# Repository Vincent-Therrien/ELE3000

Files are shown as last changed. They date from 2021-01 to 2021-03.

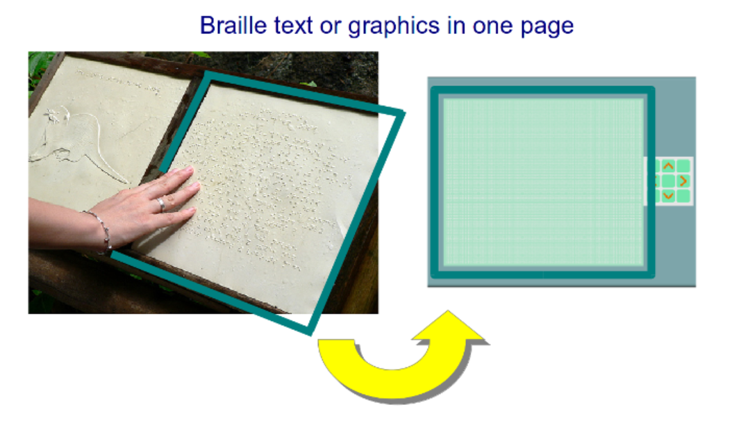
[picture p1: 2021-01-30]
html/_images/tactis_table.PNG

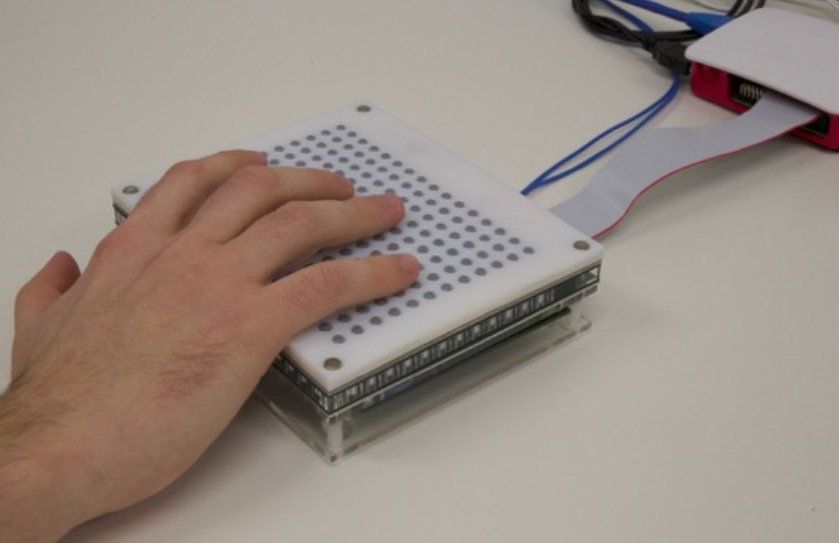
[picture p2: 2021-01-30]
html/_images/blindpad.PNG

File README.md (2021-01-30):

# ELE3000
Projet de troisième année à Polytechnique Montréal par
Vincent Therrien (vincent.therrien@polymtl.ca)

La documentation est générée avec le programme Sphinx, utilisé pour générer
la documentation officielle de Python. Les fichiers source sont écrits avec
la syntaxe Restructured Text (rst) et la documentation peut être compilée sous
plusieurs formes.

## Documentation HTML

Ouvrez le fichier "html/index.html" pour consulter la documentation sous format
HTML.

## Documentation PDF

Ouvrez le fichier "ele3000_latex.pdf" pour consulter la documentation en PDF.

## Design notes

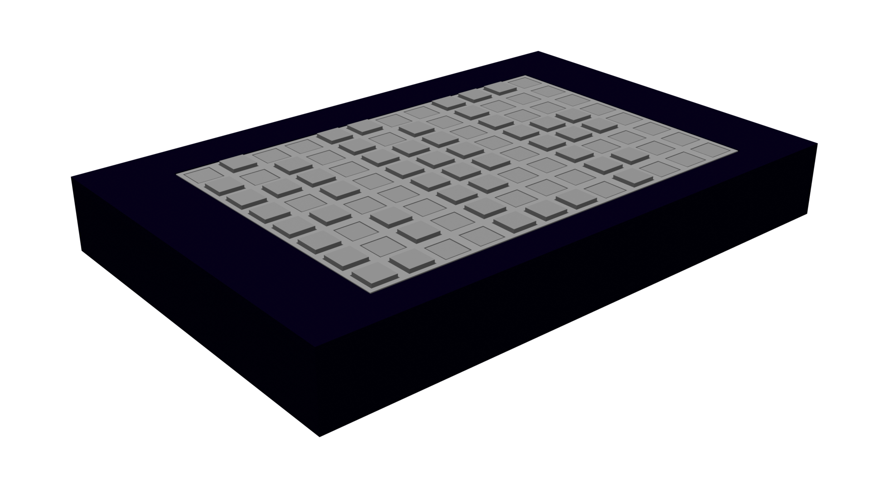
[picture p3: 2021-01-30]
html/_images/simple.png

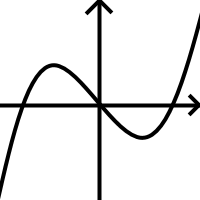
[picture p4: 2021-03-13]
application/assets/examples/degre_trois.png

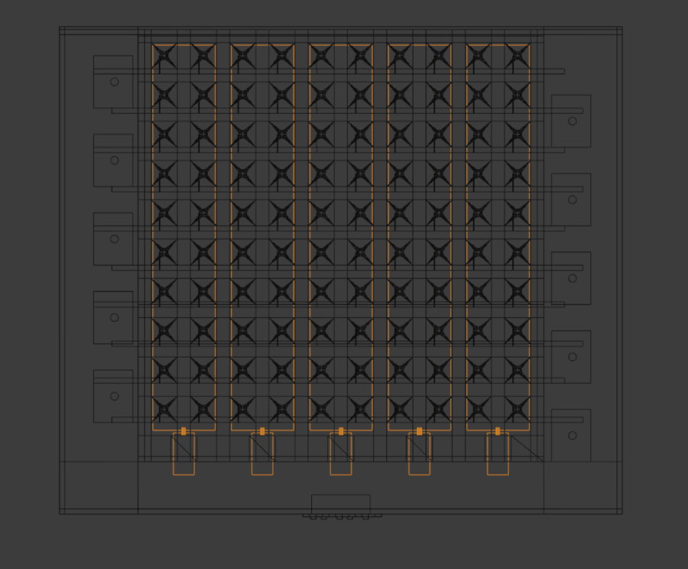
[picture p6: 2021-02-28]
html/_images/plateformes.png

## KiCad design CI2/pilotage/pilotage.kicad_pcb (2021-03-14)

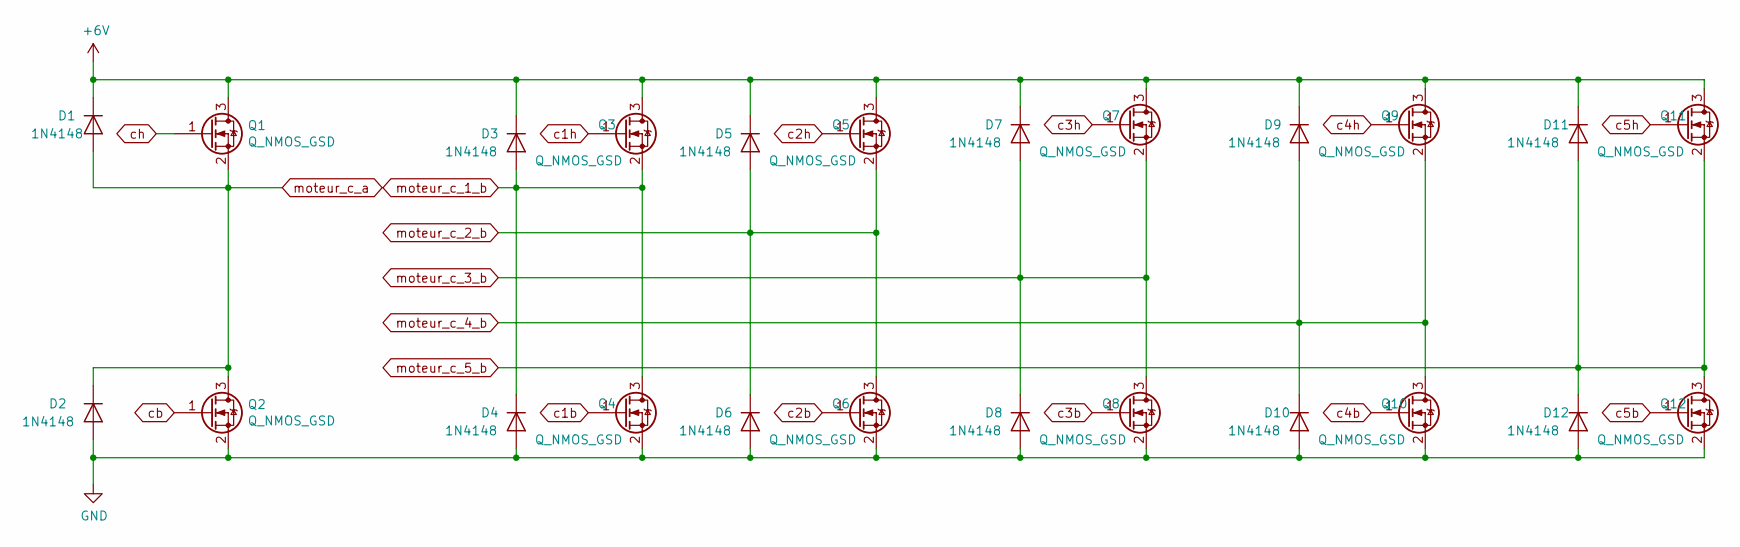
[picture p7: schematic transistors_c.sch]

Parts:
D1, D2, D3, D4, D5, D6, D7, D8, D9, D10, D11, D12: 1N4148; D_SOD-323_HandSoldering; Manufacturer Part Number 1N4148WS; DigiKey 1N4148WSFSCT-ND
Q1, Q2, Q3, Q4, Q5, Q6, Q7, Q8, Q9, Q10, Q11, Q12: Q_NMOS_GSD; SOT-23; Manufacturer Part Number DMN3404L-7; DigiKey DMN3404LDICT-ND

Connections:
+6V: D1.1 (K), D3.1 (K), D5.1 (K), D7.1 (K), D9.1 (K), D11.1 (K), Q1.3 (D), Q3.3 (D), Q5.3 (D), Q7.3 (D), Q9.3 (D), Q11.3 (D); also elsewhere on the board
GND: D2.2 (A), D4.2 (A), D6.2 (A), D8.2 (A), D10.2 (A), D12.2 (A), Q2.2 (S), Q4.2 (S), Q6.2 (S), Q8.2 (S), Q10.2 (S), Q12.2 (S); also elsewhere on the board
c1b: Q4.1 (G); also elsewhere on the board
c1h: Q3.1 (G); also elsewhere on the board
c2b: Q6.1 (G); also elsewhere on the board
c2h: Q5.1 (G); also elsewhere on the board
c3b: Q8.1 (G); also elsewhere on the board
c3h: Q7.1 (G); also elsewhere on the board
c4b: Q10.1 (G); also elsewhere on the board
c4h: Q9.1 (G); also elsewhere on the board
c5b: Q12.1 (G); also elsewhere on the board
c5h: Q11.1 (G); also elsewhere on the board
cb: Q2.1 (G); also elsewhere on the board
ch: Q1.1 (G); also elsewhere on the board
moteur_c_1_b: D3.2 (A), D4.1 (K), Q3.2 (S), Q4.3 (D); also elsewhere on the board
moteur_c_2_b: D5.2 (A), D6.1 (K), Q5.2 (S), Q6.3 (D); also elsewhere on the board
moteur_c_3_b: D7.2 (A), D8.1 (K), Q7.2 (S), Q8.3 (D); also elsewhere on the board
moteur_c_4_b: D9.2 (A), D10.1 (K), Q9.2 (S), Q10.3 (D); also elsewhere on the board
moteur_c_5_b: D11.2 (A), D12.1 (K), Q11.2 (S), Q12.3 (D); also elsewhere on the board
moteur_c_a: D1.2 (A), D2.1 (K), Q1.2 (S), Q2.3 (D); also elsewhere on the board

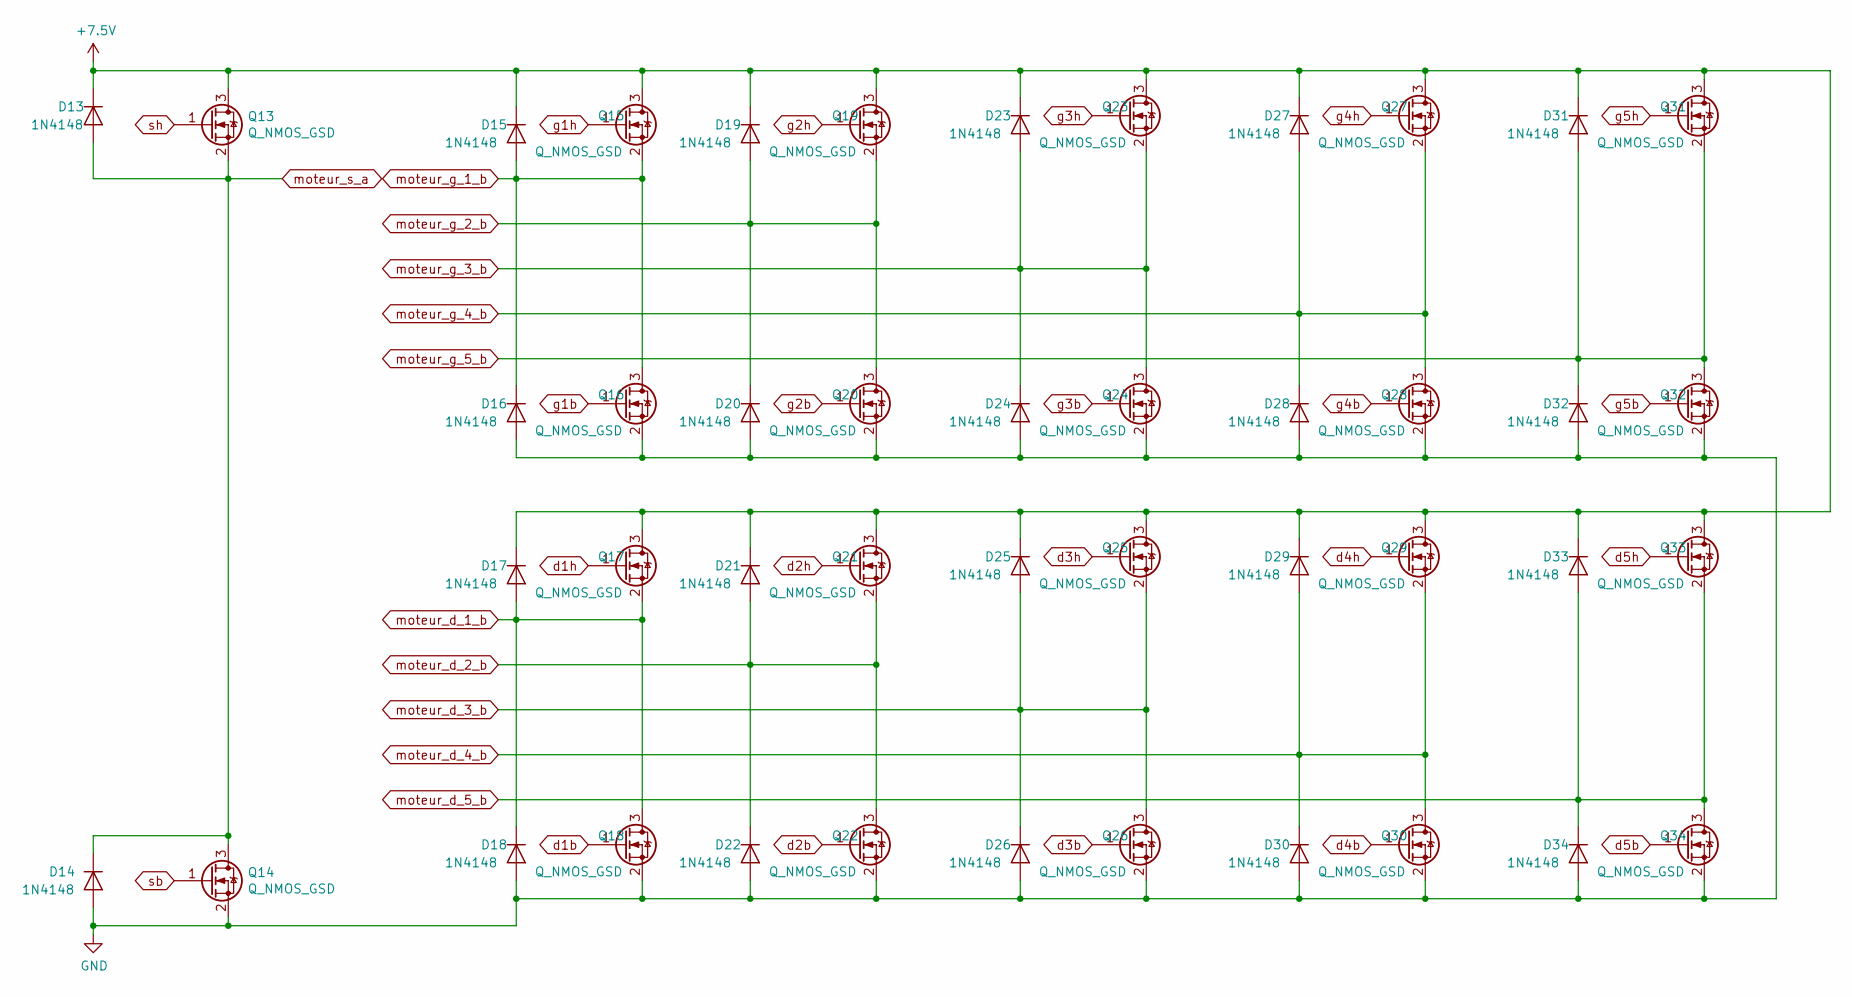
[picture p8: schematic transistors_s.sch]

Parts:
D13, D14, D15, D16, D17, D18, D19, D20, D21, D22, D23, D24, D25, D26, D27, D28, D29, D30, D31, D32, D33, D34: 1N4148; D_SOD-323_HandSoldering; Manufacturer Part Number 1N4148WS; DigiKey 1N4148WSFSCT-ND
Q13, Q14, Q15, Q16, Q17, Q18, Q19, Q20, Q21, Q22, Q23, Q24, Q25, Q26, Q27, Q28, Q29, Q30, Q31, Q32, Q33, Q34: Q_NMOS_GSD; SOT-23; Manufacturer Part Number DMN3404L-7; DigiKey DMN3404LDICT-ND

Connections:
+7.5V: D13.1 (K), D15.1 (K), D17.1 (K), D19.1 (K), D21.1 (K), D23.1 (K), D25.1 (K), D27.1 (K), D29.1 (K), D31.1 (K), D33.1 (K), Q13.3 (D), Q15.3 (D), Q17.3 (D), Q19.3 (D), Q21.3 (D), Q23.3 (D), Q25.3 (D), Q27.3 (D), Q29.3 (D), Q31.3 (D), Q33.3 (D); also elsewhere on the board
GND: D14.2 (A), D16.2 (A), D18.2 (A), D20.2 (A), D22.2 (A), D24.2 (A), D26.2 (A), D28.2 (A), D30.2 (A), D32.2 (A), D34.2 (A), Q14.2 (S), Q16.2 (S), Q18.2 (S), Q20.2 (S), Q22.2 (S), Q24.2 (S), Q26.2 (S), Q28.2 (S), Q30.2 (S), Q32.2 (S), Q34.2 (S); also elsewhere on the board
d1b: Q18.1 (G); also elsewhere on the board
d1h: Q17.1 (G); also elsewhere on the board
d2b: Q22.1 (G); also elsewhere on the board
d2h: Q21.1 (G); also elsewhere on the board
d3b: Q26.1 (G); also elsewhere on the board
d3h: Q25.1 (G); also elsewhere on the board
d4b: Q30.1 (G); also elsewhere on the board
d4h: Q29.1 (G); also elsewhere on the board
d5b: Q34.1 (G); also elsewhere on the board
d5h: Q33.1 (G); also elsewhere on the board
g1b: Q16.1 (G); also elsewhere on the board
g1h: Q15.1 (G); also elsewhere on the board
g2b: Q20.1 (G); also elsewhere on the board
g2h: Q19.1 (G); also elsewhere on the board
g3b: Q24.1 (G); also elsewhere on the board
g3h: Q23.1 (G); also elsewhere on the board
g4b: Q28.1 (G); also elsewhere on the board
g4h: Q27.1 (G); also elsewhere on the board
g5b: Q32.1 (G); also elsewhere on the board
g5h: Q31.1 (G); also elsewhere on the board
moteur_d_1_b: D17.2 (A), D18.1 (K), Q17.2 (S), Q18.3 (D); also elsewhere on the board
moteur_d_2_b: D21.2 (A), D22.1 (K), Q21.2 (S), Q22.3 (D); also elsewhere on the board
moteur_d_3_b: D25.2 (A), D26.1 (K), Q25.2 (S), Q26.3 (D); also elsewhere on the board
moteur_d_4_b: D29.2 (A), D30.1 (K), Q29.2 (S), Q30.3 (D); also elsewhere on the board
moteur_d_5_b: D33.2 (A), D34.1 (K), Q33.2 (S), Q34.3 (D); also elsewhere on the board
moteur_g_1_b: D15.2 (A), D16.1 (K), Q15.2 (S), Q16.3 (D); also elsewhere on the board
moteur_g_2_b: D19.2 (A), D20.1 (K), Q19.2 (S), Q20.3 (D); also elsewhere on the board
moteur_g_3_b: D23.2 (A), D24.1 (K), Q23.2 (S), Q24.3 (D); also elsewhere on the board
moteur_g_4_b: D27.2 (A), D28.1 (K), Q27.2 (S), Q28.3 (D); also elsewhere on the board
moteur_g_5_b: D31.2 (A), D32.1 (K), Q31.2 (S), Q32.3 (D); also elsewhere on the board
moteur_s_a: D13.2 (A), D14.1 (K), Q13.2 (S), Q14.3 (D); also elsewhere on the board
sb: Q14.1 (G); also elsewhere on the board
sh: Q13.1 (G); also elsewhere on the board

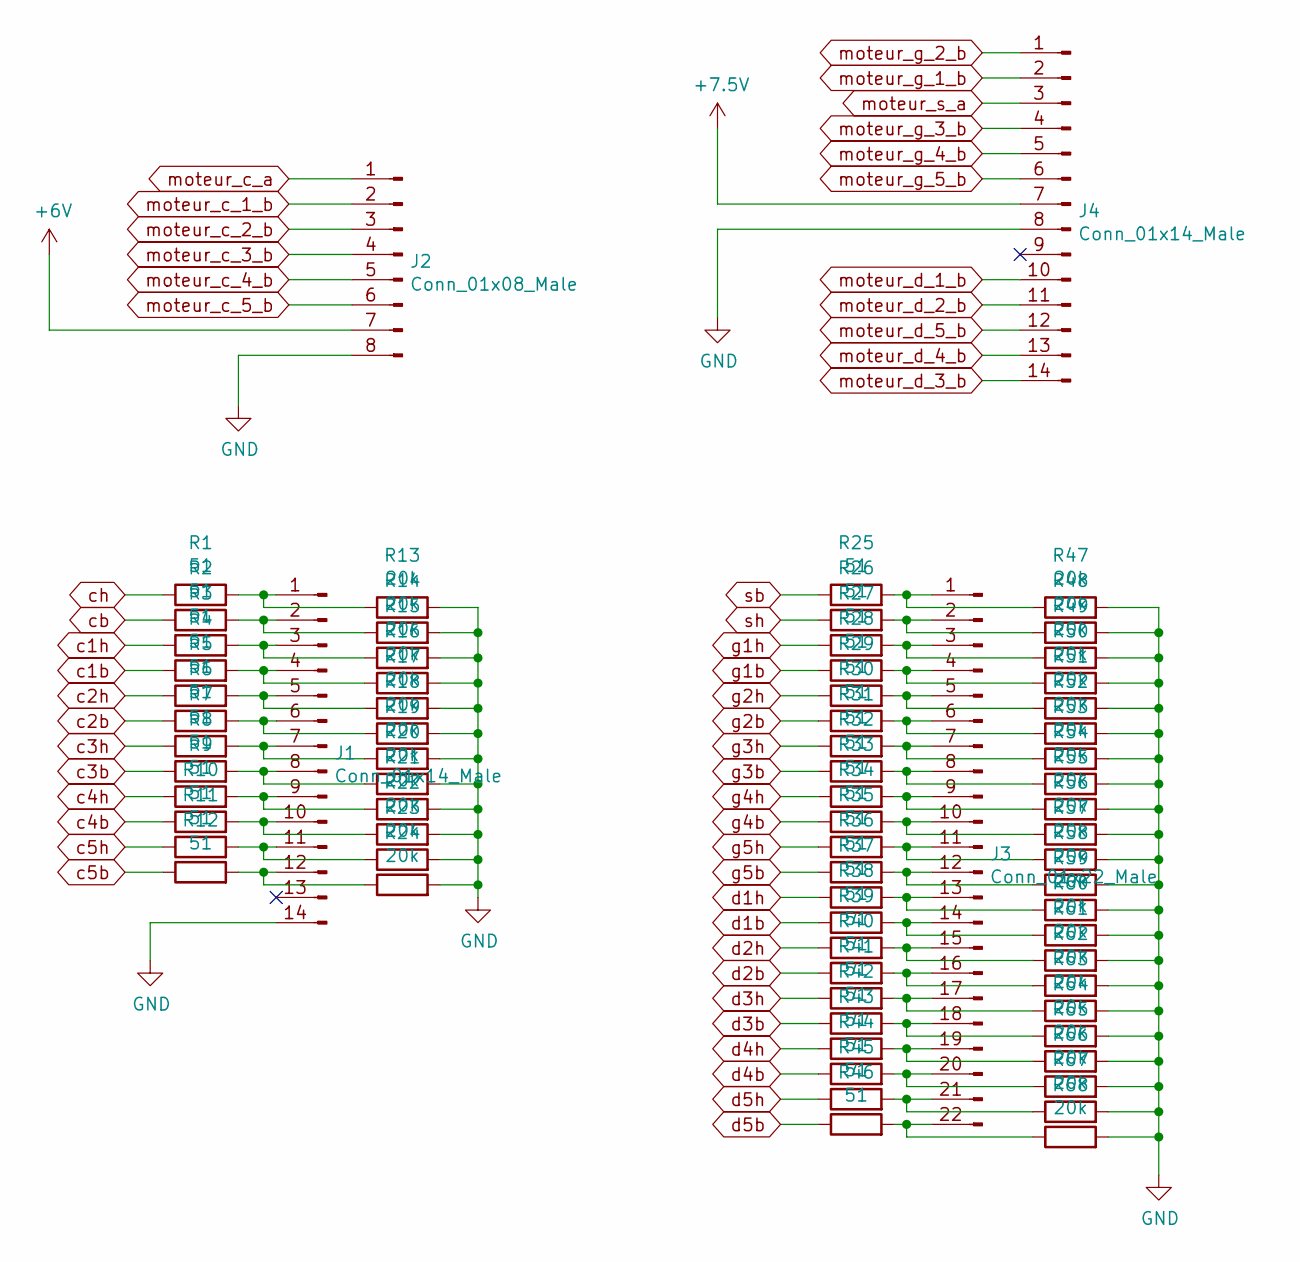
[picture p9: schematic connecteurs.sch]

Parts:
J1, J4: Conn_01x14_Male; PinHeader_1x14_P2.54mm_Vertical; Manufacturer Part Number PH1-14-UA; DigiKey 2057-PH1-14-UA-ND
J2: Conn_01x08_Male; PinHeader_1x08_P2.54mm_Vertical; Manufacturer Part Number PH1-08-UA; DigiKey 2057-PH1-08-UA-ND
J3: Conn_01x22_Male; PinHeader_1x22_P2.54mm_Vertical; Manufacturer Part Number 68000-122HLF; DigiKey 609-68000-122HLF-ND
R1, R2, R3, R4, R5, R6, R7, R8, R9, R10, R11, R12, R25, R26, R27, R28, R29, R30, R31, R32, R33, R34, R35, R36, R37, R38, R39, R40, R41, R42, R43, R44, R45, R46: 51; R_0805_2012Metric_Pad1.15x1.40mm_HandSolder; Manufacturer Part Number ESR10EZPJ510; DigiKey RHM51KCT-ND
R13, R14, R15, R16, R17, R18, R19, R20, R21, R22, R23, R24, R47, R48, R49, R50, R51, R52, R53, R54, R55, R56, R57, R58, R59, R60, R61, R62, R63, R64, R65, R66, R67, R68: 20k; R_0805_2012Metric_Pad1.15x1.40mm_HandSolder; Manufacturer Part Number ERJ-6GEYJ203V; DigiKey P20KACT-ND

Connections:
+6V: J2.7; also elsewhere on the board
+7.5V: J4.7; also elsewhere on the board
GND: J1.14, J2.8, J4.8, R13.2, R14.2, R15.2, R16.2, R17.2, R18.2, R19.2, R20.2, R21.2, R22.2, R23.2, R24.2, R47.2, R48.2, R49.2, R50.2, R51.2, R52.2, R53.2, R54.2, R55.2, R56.2, R57.2, R58.2, R59.2, R60.2, R61.2, R62.2, R63.2, R64.2, R65.2, R66.2, R67.2, R68.2; also elsewhere on the board
unnamed: J1.1, R1.2, R13.1
unnamed: J1.2, R2.2, R14.1
unnamed: J1.3, R3.2, R15.1
unnamed: J1.4, R4.2, R16.1
unnamed: J1.5, R5.2, R17.1
unnamed: J1.6, R6.2, R18.1
unnamed: J1.7, R7.2, R19.1
unnamed: J1.8, R8.2, R20.1
unnamed: J1.9, R9.2, R21.1
unnamed: J1.10, R10.2, R22.1
unnamed: J1.11, R11.2, R23.1
unnamed: J1.12, R12.2, R24.1
unnamed: J3.1, R25.2, R47.1
unnamed: J3.2, R26.2, R48.1
unnamed: J3.3, R27.2, R49.1
unnamed: J3.4, R28.2, R50.1
unnamed: J3.5, R29.2, R51.1
unnamed: J3.6, R30.2, R52.1
unnamed: J3.7, R31.2, R53.1
unnamed: J3.8, R32.2, R54.1
unnamed: J3.9, R33.2, R55.1
unnamed: J3.10, R34.2, R56.1
unnamed: J3.11, R35.2, R57.1
unnamed: J3.12, R36.2, R58.1
unnamed: J3.13, R37.2, R59.1
unnamed: J3.14, R38.2, R60.1
unnamed: J3.15, R39.2, R61.1
unnamed: J3.16, R40.2, R62.1
unnamed: J3.17, R41.2, R63.1
unnamed: J3.18, R42.2, R64.1
unnamed: J3.19, R43.2, R65.1
unnamed: J3.20, R44.2, R66.1
unnamed: J3.21, R45.2, R67.1
unnamed: J3.22, R46.2, R68.1
c1b: R4.1; also elsewhere on the board
c1h: R3.1; also elsewhere on the board
c2b: R6.1; also elsewhere on the board
c2h: R5.1; also elsewhere on the board
c3b: R8.1; also elsewhere on the board
c3h: R7.1; also elsewhere on the board
c4b: R10.1; also elsewhere on the board
c4h: R9.1; also elsewhere on the board
c5b: R12.1; also elsewhere on the board
c5h: R11.1; also elsewhere on the board
cb: R2.1; also elsewhere on the board
ch: R1.1; also elsewhere on the board
d1b: R38.1; also elsewhere on the board
d1h: R37.1; also elsewhere on the board
d2b: R40.1; also elsewhere on the board
d2h: R39.1; also elsewhere on the board
d3b: R42.1; also elsewhere on the board
d3h: R41.1; also elsewhere on the board
d4b: R44.1; also elsewhere on the board
d4h: R43.1; also elsewhere on the board
d5b: R46.1; also elsewhere on the board
d5h: R45.1; also elsewhere on the board
g1b: R28.1; also elsewhere on the board
g1h: R27.1; also elsewhere on the board
g2b: R30.1; also elsewhere on the board
g2h: R29.1; also elsewhere on the board
g3b: R32.1; also elsewhere on the board
g3h: R31.1; also elsewhere on the board
g4b: R34.1; also elsewhere on the board
g4h: R33.1; also elsewhere on the board
g5b: R36.1; also elsewhere on the board
g5h: R35.1; also elsewhere on the board
moteur_c_1_b: J2.2; also elsewhere on the board
moteur_c_2_b: J2.3; also elsewhere on the board
moteur_c_3_b: J2.4; also elsewhere on the board
moteur_c_4_b: J2.5; also elsewhere on the board
moteur_c_5_b: J2.6; also elsewhere on the board
moteur_c_a: J2.1; also elsewhere on the board
moteur_d_1_b: J4.10; also elsewhere on the board
moteur_d_2_b: J4.11; also elsewhere on the board
moteur_d_3_b: J4.14; also elsewhere on the board
moteur_d_4_b: J4.13; also elsewhere on the board
moteur_d_5_b: J4.12; also elsewhere on the board
moteur_g_1_b: J4.2; also elsewhere on the board
moteur_g_2_b: J4.1; also elsewhere on the board
moteur_g_3_b: J4.4; also elsewhere on the board
moteur_g_4_b: J4.5; also elsewhere on the board
moteur_g_5_b: J4.6; also elsewhere on the board
moteur_s_a: J4.3; also elsewhere on the board
sb: R25.1; also elsewhere on the board
sh: R26.1; also elsewhere on the board

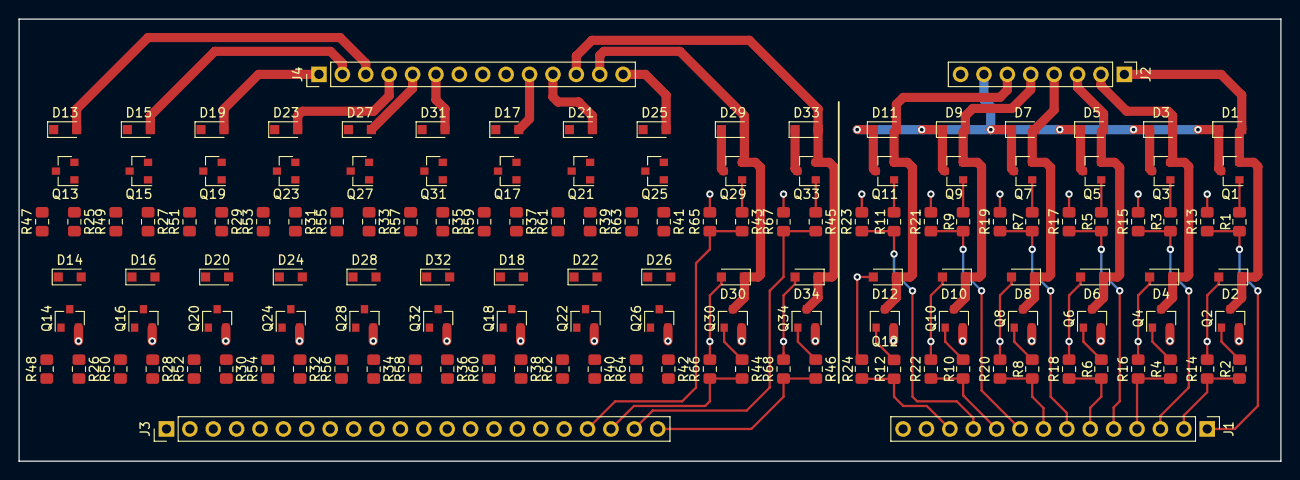
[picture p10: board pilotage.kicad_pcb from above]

Board: 2 copper layers, 137.0 x 48.0 mm, 140 parts (0 on the bottom side), 88 nets.

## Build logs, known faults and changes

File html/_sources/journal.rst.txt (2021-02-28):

Journaux hebdomadaires
======================

Janvier
-------

23
++

- Cours initial (présentation du cours et des objectifs de la semaine)
- Rédaction d'un document PDF de présentation sommaire du projet
- Recherche d'un professeur potentiellement intéressé par le projet
  dans la liste du personnel du département de GE
  (https://www.polymtl.ca/ge/notre-departement)
- Contact du professeur Richard Gourdeau et confirmation de sa direction
  du projet
- Rédaction de la description du projet ainsi que de l'échéancier;
  signature du professeur Gourdeau
- Création du journal

25
++

- Lecture sur les méthodologies de conception et le développement durable
- Second cours : validation de l'idée

27
++

- Commande de moteurs miniature pour les tester comme actionneurs
- Recherche sur les applications graphiques accessibles

30
++

- Fin de la recherche, génération de la documentation Latex

Février
-------

2
+++

- Tests mécaniques avec les moteurs.
- La force de moteurs est trop faible pour le concept initial, c'est pourquoi
  j'ai décrit une modification du concept dans la section plans.

6
+++

- Début de la réalisation des plans de l'appareil

7
+++

- Rédaction des spécifications fonctionnelles

Mars
----

Avril
-----

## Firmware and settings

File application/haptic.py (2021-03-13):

import os
import sys
import wx
import cv2
import json
import serial

def scale_bitmap(bitmap, width, height):
    image = bitmap.ConvertToImage()
    image = image.Scale(width, height, wx.IMAGE_QUALITY_HIGH)
    result = wx.Bitmap(image)
    return result

class DeviceInfo(wx.Frame):
    def __init__(self, windowTitle, strings):
        wx.Frame.__init__(self, None, title=windowTitle)
        content = ""
        for key, value in strings.items():
            content += key + "\t\t"
            if len(key) < 7:
                content += "\t"
            content += value + "\n\n"
        lbl = wx.StaticText(self, style = wx.ALIGN_LEFT | wx.EXPAND, size = (500, 500))
        lbl.SetLabel(content)
        self.Centre()
        self.Bind(wx.EVT_KEY_DOWN, self.OnKey)
    
    def OnKey(self, event):
        # Ctrl + x
        if event.ControlDown() and event.GetKeyCode() == 88:
            self.Close()
        else:
            event.Skip()


class MainFrame(wx.Frame):

    def __init__(self, *args, **kwargs):
        super(MainFrame, self).__init__(*args, **kwargs)
        # Retrieve user settings
        self.settings = {}
        with open('assets/settings.json') as f:
            self.settings = json.load(f)
        self.lexicon = {}
        self.setLanguage()
        # Runtime data
        self.cellArray = [
            [0, 0, 0, 0, 0, 0, 0, 0, 0, 0],
            [0, 0, 0, 0, 0, 0, 0, 0, 0, 0],
            [0, 0, 0, 0, 0, 0, 0, 0, 0, 0],
            [0, 0, 0, 0, 0, 0, 0, 0, 0, 0],
            [0, 0, 0, 0, 0, 0, 0, 0, 0, 0],
            [0, 0, 0, 0, 0, 0, 0, 0, 0, 0],
            [0, 0, 0, 0, 0, 0, 0, 0, 0, 0],
            [0, 0, 0, 0, 0, 0, 0, 0, 0, 0],
            [0, 0, 0, 0, 0, 0, 0, 0, 0, 0],
            [0, 0, 0, 0, 0, 0, 0, 0, 0, 0],
        ]
        self.nCol = 10
        self.nRow = 10
        self.imagePath = None
        self.subImages = []
        self.focusRectIndex = [0, 0]
        self.dimension = 1
        self.serialPort = None
        self.connectUtility = wx.CallLater(1000, self.connect)
        # Create application components.
        self.SetIcon(wx.Icon("assets/icon.png"))
        self.Centre()
        self.InitUI()
        self.SetTitle(self.lexicon["Title"])
        self.SetSize((900, 450))
        self.Centre()
        self.Bind(wx.EVT_PAINT, self.OnPaint)
        self.Bind(wx.EVT_SIZE, self.refresh)
        self.Bind(wx.EVT_KEY_DOWN, self.OnKey)
    
    def refresh(self, arg):
        self.Refresh()
        self.drawImage()
        self.refreshCells()
        self.SetFocus()
    
    def OnKey(self, event):
        # CTRL + open
        if event.ControlDown() and event.GetKeyCode() == 79:
            self.OnOpen(event)
        # CTRL info
        elif event.ControlDown() and event.GetKeyCode() == 73:
            self.OnDeviceInfo(event)
        # CTRL x
        elif event.ControlDown() and event.GetKeyCode() == 88:
            self.Close()
        # numbers
        elif event.GetKeyCode() > 48 and event.GetKeyCode() < 58:
            self.dimension = event.GetKeyCode() - 48
            self.focusRectIndex = [0, 0]
            self.refreshCells()
            self.refresh(None)
        # arrows
        elif event.GetKeyCode() == wx.WXK_DOWN:
            self.navigate('down')
        elif event.GetKeyCode() == wx.WXK_UP:
            self.navigate('up')
        elif event.GetKeyCode() == wx.WXK_LEFT:
            self.navigate('left')
        elif event.GetKeyCode() == wx.WXK_RIGHT:
            self.navigate('right')
        # Transmit image
        elif event.GetKeyCode() == wx.WXK_RETURN:
            self.transmit()
        else:
            event.Skip()

    def navigate(self, direction):
        if direction == 'down':
            self.focusRectIndex[1] += 1
            if self.focusRectIndex[1] >= self.dimension:
                self.focusRectIndex[1] = self.dimension - 1
        if direction == 'up':
            self.focusRectIndex[1] -= 1
            if self.focusRectIndex[1] < 0:
                self.focusRectIndex[1] = 0
        if direction == 'right':
            self.focusRectIndex[0] += 1
            if self.focusRectIndex[0] >= self.dimension:
                self.focusRectIndex[0] = self.dimension - 1
        if direction == 'left':
            self.focusRectIndex[0] -= 1
            if self.focusRectIndex[0] < 0:
                self.focusRectIndex[0] = 0
        self.refreshCells()
        self.Refresh()
    
    def connect(self):
        if not self.serialPort:
            try:
                self.serialPort = serial.Serial(port='COM3')
            except serial.SerialException:
                pass
        self.connectUtility = wx.CallLater(1000, self.connect)

    def transmit(self):
        if not self.serialPort:
            return
        data = b''
        for row in self.cellArray:
            for cell in row:
                data += str.encode(str(cell))
        data += b'over'
        self.serialPort.write(data)

    def setLanguage(self):
        with open('assets/languages/' + self.settings["lang"] + '.json', encoding='utf-8') as f:
            self.lexicon = json.load(f)

    def InitUI(self):
        menubar = wx.MenuBar()
        # 'File' menu
        fileMenu = wx.Menu()
        fileOpen = fileMenu.Append(wx.ID_EXIT, self.lexicon['Open'], 'Open an image')
        fileClose = fileMenu.Append(wx.ID_EXIT, self.lexicon['Close'], 'Close an image')
        fileQuit = fileMenu.Append(wx.ID_EXIT, self.lexicon['Quit'], 'Quit application')
        menubar.Append(fileMenu, '&' + self.lexicon['File'])
        # 'View' menu
        viewMenu = wx.Menu()
        viewZoomIn = viewMenu.Append(wx.ID_EXIT, self.lexicon['Zoom in'], 'Zoom in')
        viewZoomOut = viewMenu.Append(wx.ID_EXIT, self.lexicon['Zoom out'], 'Zoom out')
        viewSubdivide = viewMenu.Append(wx.ID_EXIT, self.lexicon['Subdivide'], 'Subdivide')
        viewChange = viewMenu.Append(wx.ID_EXIT, self.lexicon['Change subdivision'], 'Change subdivision')
        menubar.Append(viewMenu, '&' + self.lexicon['View'])
        # 'Language' menu
        langMenu = wx.Menu()
        viewZoomIn = langMenu.Append(wx.ID_EXIT, self.lexicon['en'], 'English')
        viewZoomOut = langMenu.Append(wx.ID_EXIT, self.lexicon['fr'], 'French')
        menubar.Append(langMenu, '&' + self.lexicon['Language'])
        # Upper bar creation
        self.SetMenuBar(menubar)
        self.Bind(wx.EVT_MENU, self.OnQuit, fileQuit)

        # Application content
        self.openButton = wx.Button(self, label=self.lexicon["ImgSelect"], pos=(0, 0), size=(450, 20))
        self.openButton.Bind(wx.EVT_BUTTON, self.OnOpen)
        self.deviceButton = wx.Button(self, label=self.lexicon["Device"],  pos=(450, 0), size=(450, 20))
        self.deviceButton.Bind(wx.EVT_BUTTON, self.OnDeviceInfo)

    def OnQuit(self, e):
        self.Close()
    
    def OnOpen(self, event):
        with wx.FileDialog(self, "Open an image file",
                wildcard=("Raster graphic file (*.png;*.jpeg;*.bmp)|*.png;*.jpeg;*.bmp|"
                    + "Vector graphic file (*.svg)|*.svg"),
                style=wx.FD_OPEN | wx.FD_FILE_MUST_EXIST) as fileDialog:
            if fileDialog.ShowModal() == wx.ID_CANCEL:
                return
            self.imagePath = fileDialog.GetPath()
            self.dimension = 1
            self.focusRectIndex = [0, 0]
            self.refresh(None)
    
    def OnDeviceInfo(self, event):
        if self.serialPort:
            state = self.lexicon["Active"]
        else:
            state = self.lexicon["Inactive"]
        frame = DeviceInfo(self.lexicon["DeviceWindow"],
            {self.lexicon["SerieNumber"] : "0000000001",
             self.lexicon["Resolution"] : '(' + str(self.nRow) + ' X ' + str(self.nCol) + ')',
             self.lexicon["Status"] : state})
        frame.Show()
    
    def refreshCells(self):
        if not self.imagePath:
            return
        image = cv2.imread(self.imagePath)
        gray = cv2.cvtColor(image, cv2.COLOR_BGR2GRAY)
        h, w = gray.shape
        h /= self.dimension
        w /= self.dimension
        resized = gray[int(self.focusRectIndex[1]*h) : int((self.focusRectIndex[1]+1)*h),
            int(self.focusRectIndex[0]*w) : int((self.focusRectIndex[0]+1)*w) ]
        h, w = resized.shape
        sub_w = w / self.nCol
        sub_h = h / self.nRow
        for row in range(self.nRow):
            for col in range(self.nCol):
                x = col*sub_w
                y = row*sub_h
                subdivision = resized[int(y):int(y + sub_h), int(x):int(x + sub_w)]
                mean = int(subdivision.mean())
                if mean < 200:
                    self.cellArray[row][col] = 1
                else:
                    self.cellArray[row][col] = 0
    
    def drawImage(self):
        if not self.imagePath:
            return
        if self.subImages:
            for sub in self.subImages:
                sub.Destroy()
        self.subImages.clear()
        # Draw image subdivisions
        w, h = self.GetSize()
        _, minH = self.openButton.GetSize()
        bitmap = wx.Bitmap(self.imagePath, wx.BITMAP_TYPE_ANY)
        imageH = bitmap.GetHeight()
        imageW = bitmap.GetWidth()
        displayH = h - minH - 80
        displayW = w/2 - 20
        displaySubH = displayH / self.dimension - 6
        displaySubW = displayW / self.dimension - 6
        imageSubH = imageH / self.dimension
        imageSubW = imageW / self.dimension
        img = bitmap.ConvertToImage()
        for row in range(self.dimension):
            for col in range(self.dimension):
                i = img.GetSubImage(wx.Rect(col*imageSubW, row*imageSubH, imageSubW, imageSubH))
                b = i.ConvertToBitmap()
                b = scale_bitmap(b, int(displaySubW), int(displaySubH))
                self.subImages.append(wx.StaticBitmap(self, wx.ID_ANY, b,
                    pos=(13 + int(col*(displaySubW+6)), minH + 13 + int(row*(displaySubH+6)))))

    def OnPaint(self,evt):
        dc = wx.PaintDC(self)
        dc.Clear()
        dc.SetPen(wx.Pen('black'))
        w, h = self.GetSize()
        _, minH = self.openButton.GetSize()
        self.openButton.SetSize(0, 0, w/2, minH)
        self.deviceButton.SetSize(w/2, 0, w/2, minH)
        # Paint image
        dc.SetBrush(wx.Brush('grey'))
        dc.DrawRectangle(10, minH + 10, w/2 - 20, h - minH - 80)
        if self.subImages:
            dc.SetBrush(wx.Brush('blue'))
            rectW = ((w/2) - 20) / self.dimension
            rectH = (h - minH - 80) / self.dimension
            dc.DrawRectangle(7 + (self.focusRectIndex[0] * rectW),
                 minH + 7 + (self.focusRectIndex[1] * rectH), rectW + 6, rectH + 6)
        # Paint preview
        dc.SetBrush(wx.Brush('white'))
        dc.DrawRectangle(w/2 + 10, minH + 10, w/2 - 40, h - minH - 80)
        paddingX = w / 10
        paddingY = h / 5
        if paddingX > paddingY:
            squareS = (w/2 - paddingX - paddingX) / self.nRow
        else:
            squareS = (h - minH - paddingY - paddingY) / self.nCol
        self.refreshCells()
        for row in range(0, self.nRow):
            for col in range(0, self.nCol):
                position = (row * self.nCol) + col
                if self.cellArray[row][col]:
                    dc.SetBrush(wx.Brush('black'))
                else:
                    dc.SetBrush(wx.Brush('white'))
                dc.DrawRectangle(w/2 + paddingX + col*squareS,
                    paddingY + row * squareS,
                    squareS,
                    squareS)

def main():
    # Change working directory to script location to enable content retrival.
    abspath = os.path.abspath(__file__)
    current_dir_name = os.path.dirname(abspath)
    os.chdir(current_dir_name)
    # Begin de application.
    app = wx.App()
    frame = MainFrame(None)
    frame.Show()
    app.MainLoop()

if __name__ == '__main__':
    main()

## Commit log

2021-01-30 Ajout de la documentation
2021-01-30 Faute de frappe
2021-02-28 Mise à jour de la réalisation physique de l'appareil
2021-03-13 Ajout de l'application
2021-03-14 Ajout du PCB
    [connecteurs.sch, microcontroleur.sch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]
